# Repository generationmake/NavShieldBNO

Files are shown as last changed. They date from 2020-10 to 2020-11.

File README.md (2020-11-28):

# NavShieldBNO
Navigation shield for Arduino with Bosch BNO055, BNO080 or BNO085

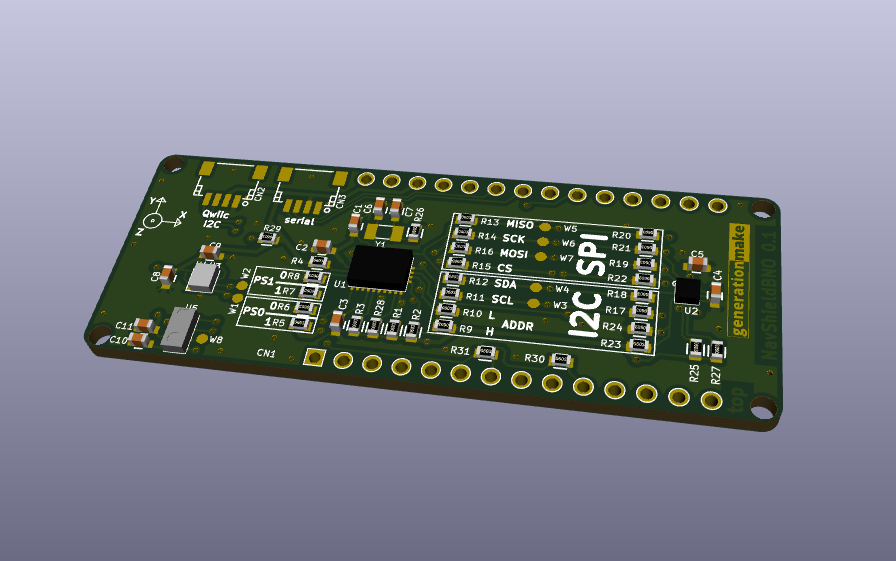
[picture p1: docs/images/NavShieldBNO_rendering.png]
NavShieldBNO rendering


## pin usage

### Arduino MKR connector CN1

| **Pin** | **Pin Name** | **Signal** | **Description** |
|:---:|:---:|:---:|:---:|
| 1 | AREF | | |
| 2 | DAC0/A0 | | |
| 3 | A1 | | |
| 4 | A2 | | |
| 5 | A3 | | |
| 6 | A4 | | |
| 7 | A5 | WAKE_2 | option 2 for WAKE from BNO085 |
| 8 | A6 | | |
| 9 | 0 | | |
| 10 | 1 | WAKE_1 | option 1 for WAKE from BNO085 |
| 11 | 2 | BMP388_CS | chip select for BMP388 |
| 12 | 3 | | |
| 13 | 4 | | |
| 14 | 5 | BNO085_CS | chip select for BNO085 |
| 15 | 6 | BMP388_INT | interrupt from BMP388 |
| 16 | 7 | BNO085_INT | interrupt from BNO085 |
| 17 | 8/MOSI | SPI_MOSI | to sensors if SPI option is used |
| 18 | 9/SCK | SPI_SCK | to sensors if SPI option is used |
| 19 | 10/MISO | SPI_MISO | to sensors if SPI option is used |
| 20 | 11/SDA | I2C_SDA | to sensors if I2C option is used |
| 21 | 12/SCL | I2C_SCL | to sensors if I2C option is used |
| 22 | 13/RX | SERIAL_RX | to connector CN3 |
| 23 | 14/TX | SERIAL_TX | to connector CN3 |
| 24 | RESET | RESET | Reset for BNO085 |
| 25 | GND | GND | |
| 26 | VCC | 3V3-rail | supply voltage for board |
| 27 | VIN | | |
| 28 | 5V0 | | |

### Qwiic I2C connector CN2

compatible to Sparkfun Qwiic. JST SH 1mm 4-pin.

| **Pin** | **Signal** | **Description** |
|:---:|:---:|:---:|
| 1 | GND | |
| 2 | VCC | |
| 3 | I2C_SDA | |
| 4 | I2C_SCL | |

### serial connector CN3

JST SH 1mm 4-pin.

| **Pin** | **Signal** | **Description** |
|:---:|:---:|:---:|
| 1 | GND | |
| 2 | VCC | |
| 3 | SERIAL_TX | |
| 4 | SERIAL_RX | |

## PCB

### Top

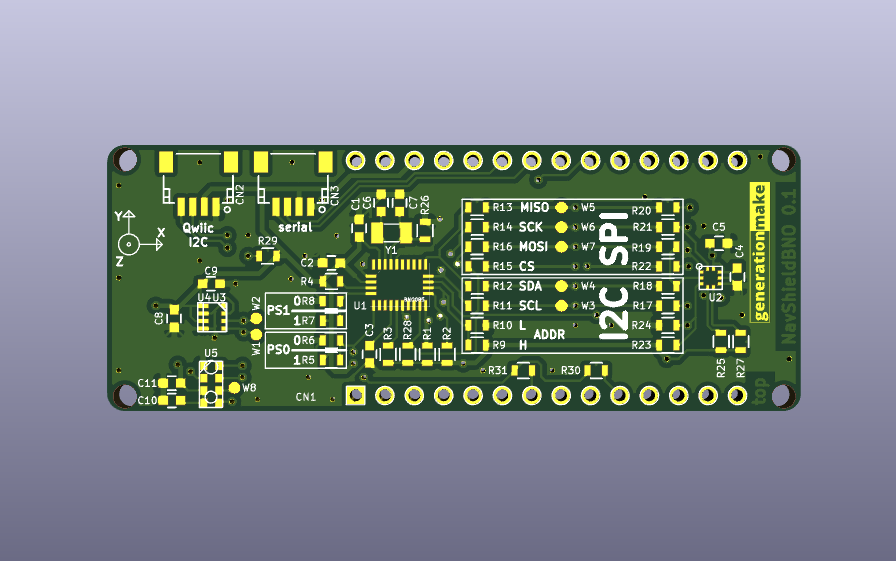
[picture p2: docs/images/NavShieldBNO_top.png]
NavShieldBNO PCB top


### Bottom

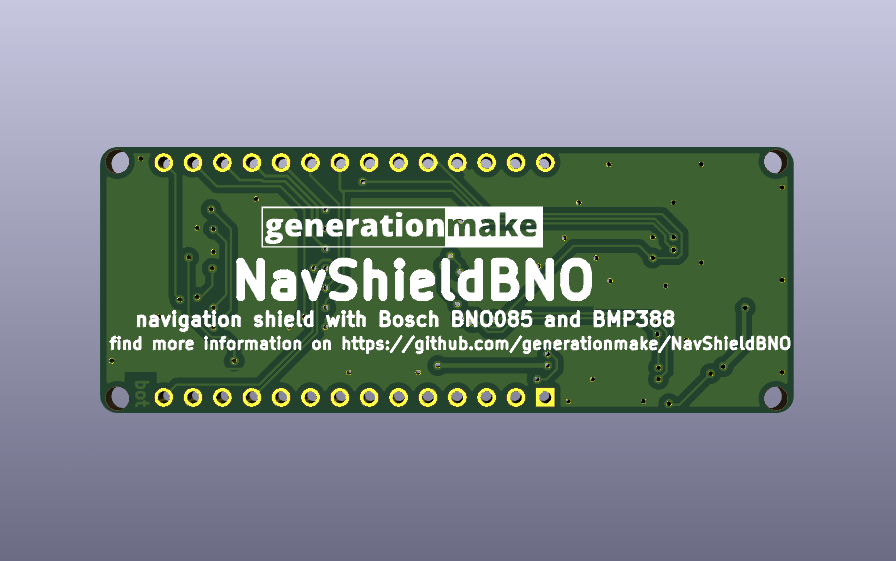
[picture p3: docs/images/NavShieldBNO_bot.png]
NavShieldBNO PCB bot


## Variants

It is possible to mount a BNO055 instead of the BNO085. The BNO055 only supports the I2C interface.

### BOM changes

The following parts need to be changed:

| part | BNO085 variant | BNO055 variant |
|:----:|:---:|:---:|
| R1 | 10k | DNI |
| R2 | 10k | DNI |
| R5 | 10k | DNI |
| R6 | DNI | 10k |
| R7 | 10k | DNI |
| R8 | DNI | 10k |
| R10  | DNI | 0R |
| R11  | DNI | 0R |
| R12  | DNI | 0R |
| R13  | 0R | DNI |
| R14  | 0R | DNI |
| R15  | 0R | DNI |
| R16  | 0R | DNI |
| C8 | 100nF | DNI |
| C9 | 100nF | DNI |
| C10  | 100nF | DNI |
| C11  | 100nF | DNI |
| U1 | BNO085 | BMP055 |
| U3 | BMP280 | DNI |
| U4 | BME280 | DNI |
| U5 | VCNL4040 | DNI |

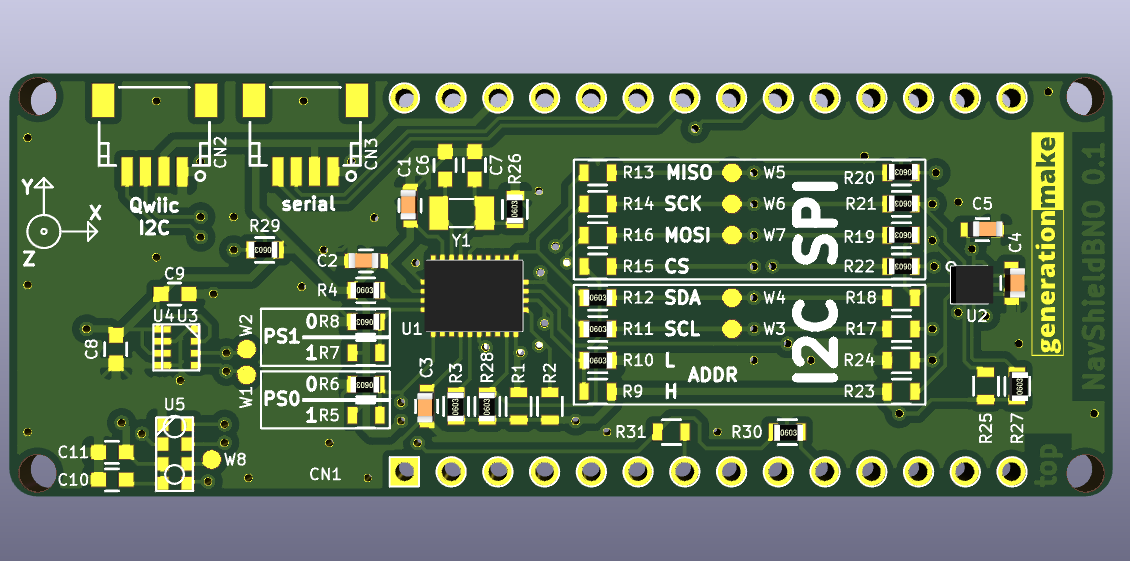
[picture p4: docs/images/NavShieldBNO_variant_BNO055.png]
NavShieldBNO PCB Variant BNO055


## Resources

### Datasheets

 * *BNO080* https://cdn.sparkfun.com/assets/2/b/9/0/6/DS-14686-BNO080.pdf
 * *BMP388* https://www.bosch-sensortec.com/media/boschsensortec/downloads/datasheets/bst-bmp388-ds001.pdf
 * *BNO055* https://www.bosch-sensortec.com/media/boschsensortec/downloads/datasheets/bst-bno055-ds000.pdf

### Arduino Libraries

* [107-Arduino-BNO085](https://github.com/107-systems/107-Arduino-BNO085)
* [107-Arduino-BMP388](https://github.com/107-systems/107-Arduino-BMP388)

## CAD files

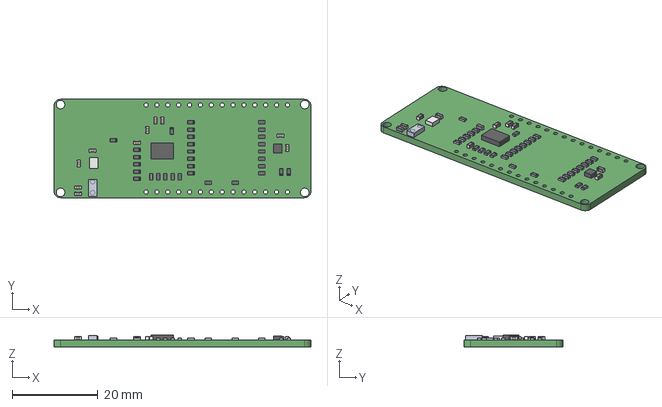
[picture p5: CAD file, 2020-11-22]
NavShieldBNO.step
60.0 x 23.0 x 2.83 mm

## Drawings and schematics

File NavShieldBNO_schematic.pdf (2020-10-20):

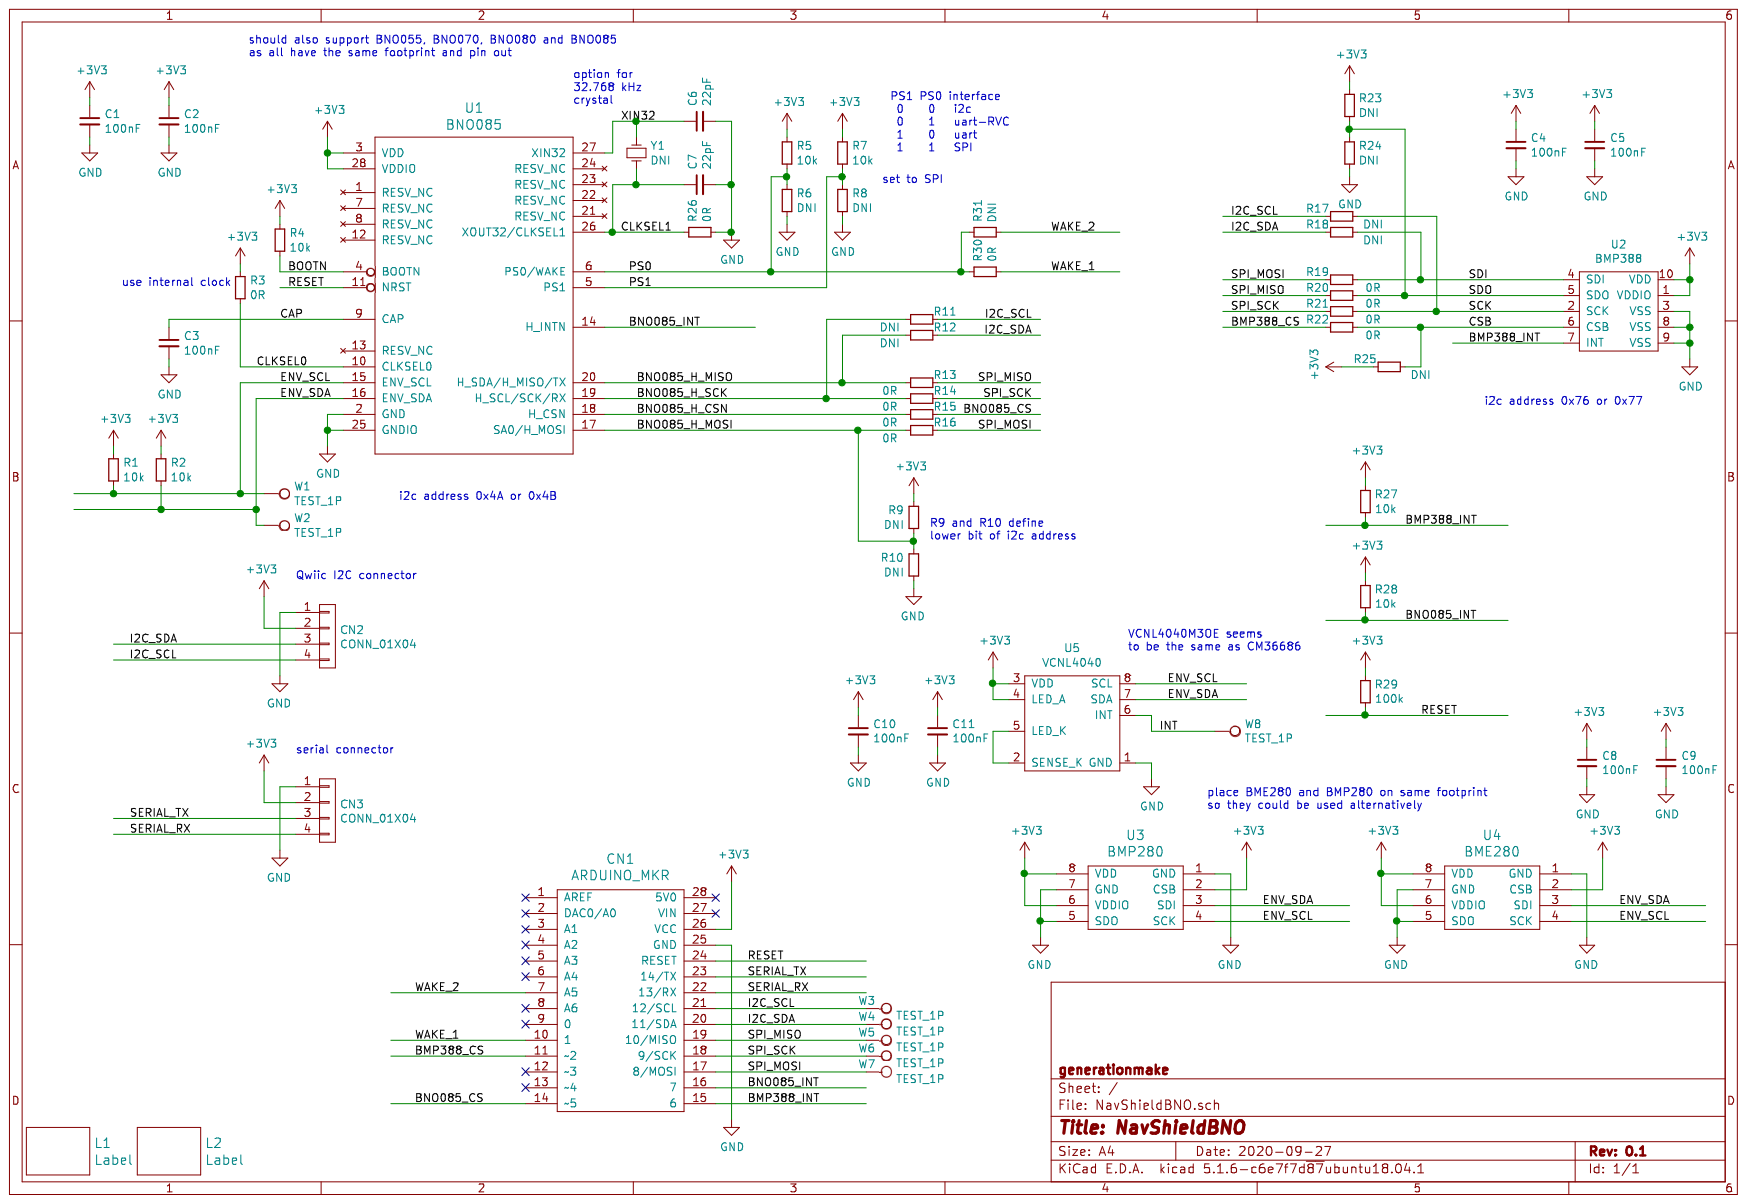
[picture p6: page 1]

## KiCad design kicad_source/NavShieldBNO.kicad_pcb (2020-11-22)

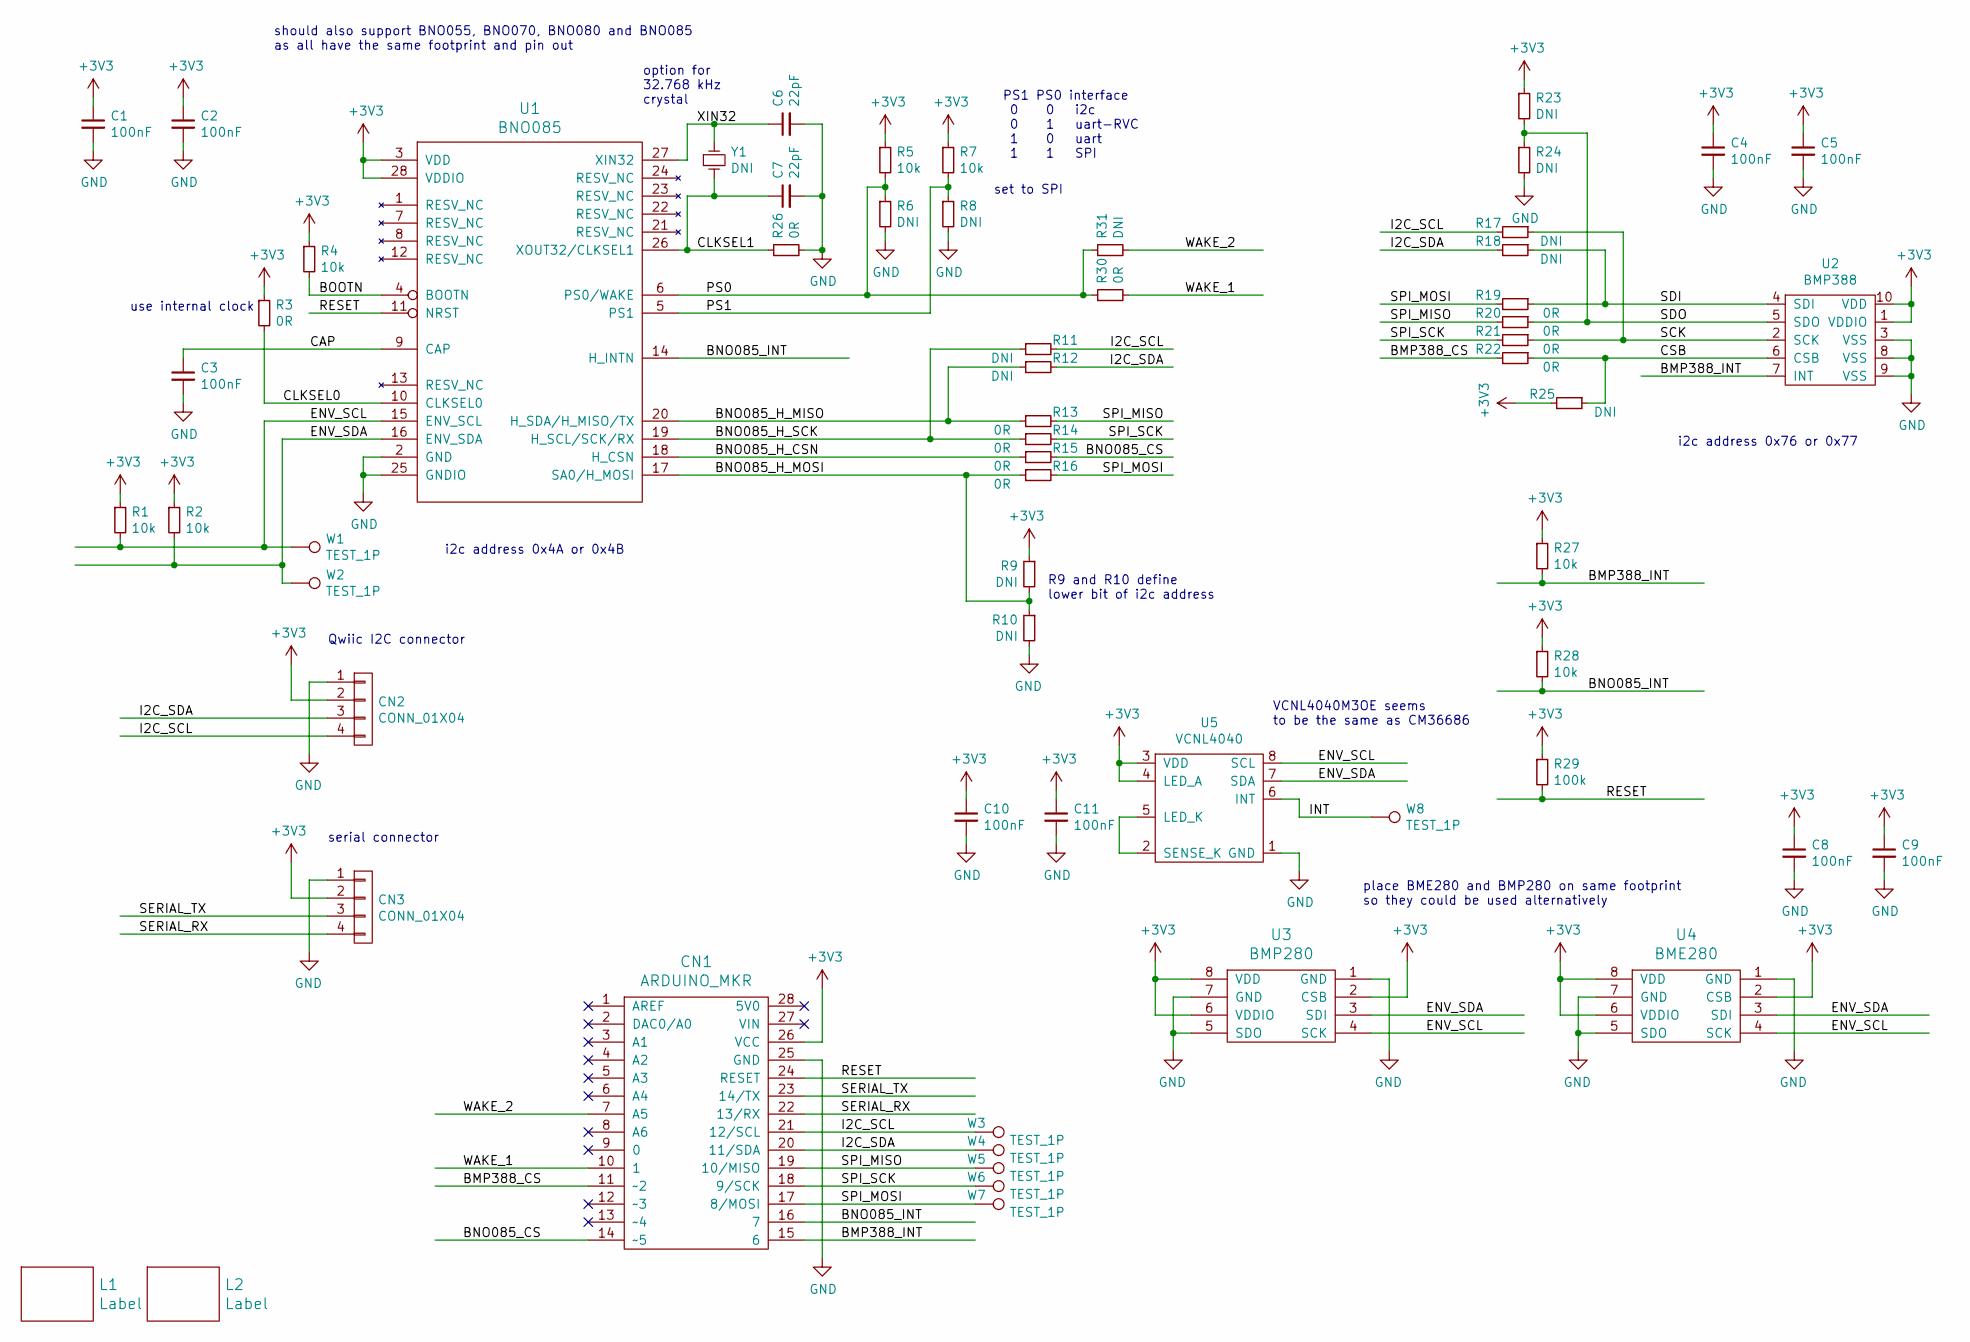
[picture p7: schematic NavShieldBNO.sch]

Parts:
C1, C2, C3, C4, C5, C8, C9, C10, C11: 100nF; C_0603
C6, C7: 22pF; C_0603
CN1: ARDUINO_MKR; ARDUINO_MKR_HOLES
CN2, CN3: CONN_01X04; Connectors_JST_SM04B-SRSS-TB
L1: Label; generationmake_small_solder
L2: Label; generationmake_logo
R1, R2, R4, R5, R7, R27, R28: 10k; R_0603
R3, R13, R14, R15, R16, R19, R20, R21, R22, R26, R30: 0R; R_0603
R6, R8, R9, R10, R11, R12, R17, R18, R23, R24, R25, R31: DNI; R_0603
R29: 100k; R_0603
U1: BNO085; LGA-28-5832
U2: BMP388
U3: BMP280
U4: BME280
U5: VCNL4040
W1, W2, W3, W4, W5, W6, W7, W8: TEST_1P; SolderWirePad_single_1mmSMD
Y1: DNI; Crystal_SMD_3.2x1.5mm_2Pad

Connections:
+3V3: C1.1, C2.1, C4.1, C5.1, C8.1, C9.1, C10.1, C11.1, CN1.26 (VCC), CN2.2, CN3.2, R1.1, R2.1, R3.1, R4.1, R5.1, R7.1, R9.1, R23.1, R25.2, R27.1, R28.1, R29.1, U1.3 (VDD), U1.28 (VDDIO), U2.1 (VDDIO), U2.10 (VDD), U3.2 (CSB), U3.6 (VDDIO), U3.8 (VDD), U4.2 (CSB), U4.6 (VDDIO), U4.8 (VDD), U5.3 (VDD), U5.4 (LED_A)
/BMP388_CS: CN1.11 (~~2), R22.2
/BMP388_INT: CN1.15 (6), R27.2, U2.7 (INT)
/BNO085_CS: CN1.14 (~~5), R15.2
/BNO085_H_CSN: R15.1, U1.18 (H_CSN)
/BNO085_H_MISO: R12.1, R13.1, U1.20 (H_SDA/H_MISO/TX)
/BNO085_H_MOSI: R9.2, R10.1, R16.1, U1.17 (SA0/H_MOSI)
/BNO085_H_SCK: R11.1, R14.1, U1.19 (H_SCL/SCK/RX)
/BNO085_INT: CN1.16 (7), R28.2, U1.14 (H_INTN)
/BOOTN: R4.2, U1.4 (BOOTN)
/CAP: C3.1, U1.9 (CAP)
/CLKSEL0: R3.2, U1.10 (CLKSEL0)
/CLKSEL1: C7.1, R26.1, U1.26 (XOUT32/CLKSEL1), Y1.2
/CSB: R22.1, R25.1, U2.6 (CSB)
/ENV_SCL: R1.2, U1.15 (ENV_SCL), U3.4 (SCK), U4.4 (SCK), U5.8 (SCL), W1.1
/ENV_SDA: R2.2, U1.16 (ENV_SDA), U3.3 (SDI), U4.3 (SDI), U5.7 (SDA), W2.1
/I2C_SCL: CN1.21 (12/SCL), CN2.4, R11.2, R17.2, W3.1
/I2C_SDA: CN1.20 (11/SDA), CN2.3, R12.2, R18.2, W4.1
/INT: U5.6 (INT), W8.1
/PS0: R5.2, R6.1, R30.1, R31.1, U1.6 (PS0/WAKE)
/PS1: R7.2, R8.1, U1.5 (PS1)
/RESET: CN1.24 (RESET), R29.2, U1.11 (NRST)
/SCK: R17.1, R21.1, U2.2 (SCK)
/SDI: R18.1, R19.1, U2.4 (SDI)
/SDO: R20.1, R23.2, R24.1, U2.5 (SDO)
/SERIAL_RX: CN1.22 (13/RX), CN3.4
/SERIAL_TX: CN1.23 (14/TX), CN3.3
/SPI_MISO: CN1.19 (10/MISO), R13.2, R20.2, W5.1
/SPI_MOSI: CN1.17 (8/MOSI), R16.2, R19.2, W7.1
/SPI_SCK: CN1.18 (9/SCK), R14.2, R21.2, W6.1
/WAKE_1: CN1.10 (1), R30.2
/WAKE_2: CN1.7 (A5), R31.2
/XIN32: C6.1, U1.27 (XIN32), Y1.1
GND: C1.2, C2.2, C3.2, C4.2, C5.2, C6.2, C7.2, C8.2, C9.2, C10.2, C11.2, CN1.25 (GND), CN2.1, CN3.1, R6.2, R8.2, R10.2, R24.2, R26.2, U1.2 (GND), U1.25 (GNDIO), U2.3 (VSS), U2.8 (VSS), U2.9 (VSS), U3.1 (GND), U3.5 (SDO), U3.7 (GND), U4.1 (GND), U4.5 (SDO), U4.7 (GND), U5.1 (GND)
unnamed: U5.2 (SENSE_K), U5.5 (LED_K)

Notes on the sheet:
i2c address 0x76 or 0x77
set to SPI
use internal clock
i2c address 0x4A or 0x4B
should also support BNO055, BNO070, BNO080 and BNO085 as all have the same footprint and pin out
Qwiic I2C connector
serial connector
R9 and R10 define lower bit of i2c address
PS1 PS0 interface 0 0 i2c 0 1 uart-RVC 1 0 uart 1 1 SPI
option for 32.768 kHz crystal
place BME280 and BMP280 on same footprint so they could be used alternatively
VCNL4040M3OE seems to be the same as CM36686

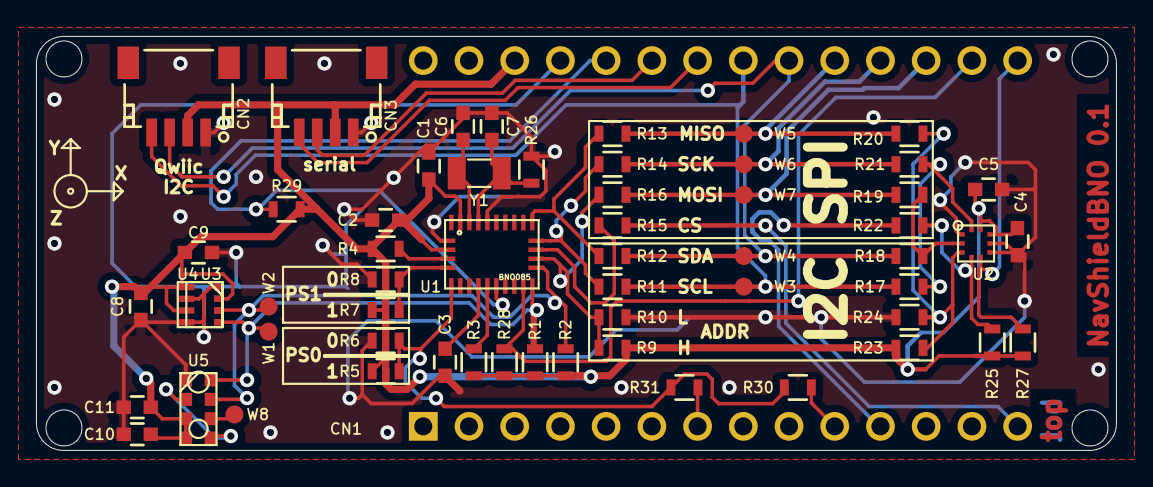
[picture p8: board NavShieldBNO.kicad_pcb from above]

Board: 2 copper layers, 60.0 x 23.0 mm, 61 parts (1 on the bottom side), 35 nets.

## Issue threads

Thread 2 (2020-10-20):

support for BMP390L

generationmake, 2020-10-20:
The BMP390L is the successor of the BMP388 and has better performance. It should be pin compatible but needs to be tested.
https://www.bosch-sensortec.com/products/environmental-sensors/pressure-sensors/bmp390l/

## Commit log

2020-09-04 added kicad project
    [NavShieldBNO.kicad_pcb, NavShieldBNO.sch]
2020-09-06 updated schematic, added schematic pdf
    [NavShieldBNO.sch]
2020-09-06 annotated schematic
    [NavShieldBNO.sch]
2020-09-08 added pull up on INT and reset lines
    [NavShieldBNO.sch]
2020-09-08 connected CLKSEL1 to GND via resistor
    [NavShieldBNO.sch]
2020-09-09 moved BNO085_CS to D5, updated schematic pdf
    [NavShieldBNO.sch]
2020-09-15 Adding links to Arduino libraries for BNO085/BMP388
2020-09-16 added WAKE signal to Arduino connector
    [NavShieldBNO.sch]
2020-09-16 added connector for I2C and serial
    [NavShieldBNO.sch]
2020-09-16 started placement
    [NavShieldBNO.kicad_pcb]
2020-09-16 first draft of layout
    [NavShieldBNO.kicad_pcb]
2020-09-16 added images of PCBs
2020-09-17 updated schematic pdf
2020-09-22 made pcb bigger and added holes for Arduino MKR
    [NavShieldBNO.kicad_pcb, NavShieldBNO.sch]
2020-09-24 added second option for wake on A5, rearranged placement of option resistors and added description in silk screen
    [NavShieldBNO.kicad_pcb, NavShieldBNO.sch]
2020-09-25 added option for 32 kHz crystal, updated images and pdf
    [NavShieldBNO.kicad_pcb, NavShieldBNO.sch]
2020-09-27 added BME280/BMP280
    [NavShieldBNO.kicad_pcb, NavShieldBNO.sch]
2020-09-27 added Vishay VCNL4040
    [NavShieldBNO.kicad_pcb, NavShieldBNO.sch]
2020-09-27 added logo, updated images and pdf
    [NavShieldBNO.kicad_pcb, NavShieldBNO.sch]
2020-09-27 updated layout, made DRC, updated silk screen
    [NavShieldBNO.kicad_pcb, NavShieldBNO.sch]
2020-11-22 updated some footprints with 3d models
    [NavShieldBNO.kicad_pcb]
2020-11-22 updated rendering of board
2020-11-22 added step file of board
    [NavShieldBNO.step]
